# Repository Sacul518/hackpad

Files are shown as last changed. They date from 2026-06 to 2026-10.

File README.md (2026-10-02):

# Hackpad

A custom 9-key mechanical macropad with a rotary encoder and OLED display, built around the **Seeed XIAO RP2040**. Designed from scratch in KiCad as part of [Hack Club's Hackpad YSWS](https://hackpad.hackclub.com/).

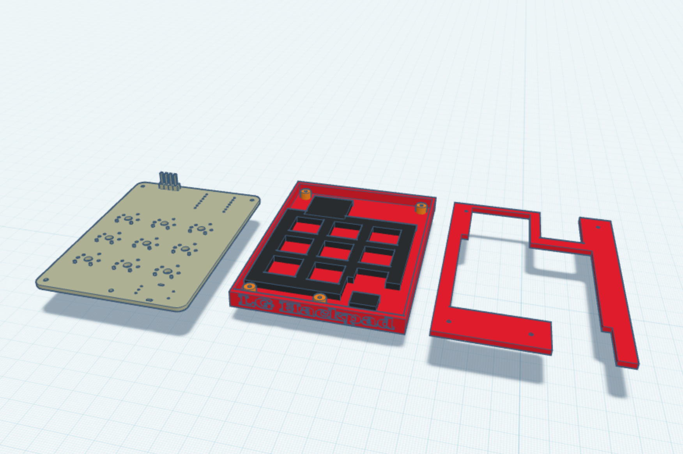
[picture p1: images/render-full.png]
Full render — PCB, case tray and top frame


## Inspiration & challenges

I wanted a macropad that isn't just static keys but actually adapts to what I'm
doing — so the **rotary encoder browses through profiles** (turn to preview on
the OLED, click to confirm) and **every one of the 9 keys is freely
configurable** through a desktop app, either as a key combo or a custom script.

Biggest challenges as a first-timer:
- **Routing a 2-layer board by hand** around the matrix diodes and the encoder
  without crossing nets, while keeping a clean GND pour.
- **Fitting everything under 100 × 100 mm** — I had to shrink the outline and
  move the bottom edge and mounting holes without breaking the carefully placed
  switch matrix (final size: **68 × 99.68 mm**).
- **An open case without print supports** — exposed XIAO RP2040 because it looks
  cool, plus an anti-flex support grid under the PCB so the board doesn't bend
  when pressing keys.

## Features

- **3×3 mechanical switch matrix** (9× Cherry MX–compatible keys) with per-key 1N4148 diodes for full n-key rollover
- **Rotary encoder** (EC11) with push button — for volume, scrolling, etc.
- **0.96" OLED display** (SSD1306, I²C) for layer/status info
- **Seeed XIAO RP2040** microcontroller (through-hole)
- Custom PCB + 3D-printed case

## Bill of materials (BOM)

| # | Qty | Part | Notes |
|---|-----|---|---|
| 1 | 1 | Seeed XIAO RP2040 | main MCU (through-hole) |
| 2 | 9 | Cherry MX–compatible switch | PCB-mount, 3×3 matrix |
| 3 | 9 | 1N4148 diode | THT, per-key (COL→ROW), n-key rollover |
| 4 | 1 | EC11 rotary encoder w/ push switch | profile browser |
| 5 | 1 | SSD1306 0.96" OLED (I²C, 4-pin) | status / profile preview |
| 6 | 1 | Custom PCB (2-layer) | 68 × 99.68 mm |
| 7 | 1 | 3D-printed case (tray + open top frame) | PLA, no supports |
| 8 | 4 | M2 screw | case mounting |
| 9 | 9 | Keycap (DSA) + 1 encoder knob | from the kit |

A machine-readable version is also provided as [`bom.csv`](bom.csv).

### Pin mapping (XIAO RP2040)

| Function | Pin | | Function | Pin |
|---|-----|---|---|-----|
| COL0 | D0 | | ROW0 | D3 |
| COL1 | D1 | | ROW1 | D6 |
| COL2 | D2 | | ROW2 | D7 |
| Encoder A | D8 | | OLED SDA | D4 |
| Encoder B | D9 | | OLED SCL | D5 |
| Encoder SW | D10 | | | |

Matrix is wired **COL2ROW**: column → switch → diode anode, diode cathode → row.

## Gallery

| Schematic | PCB | Case |
|---|-----|---|
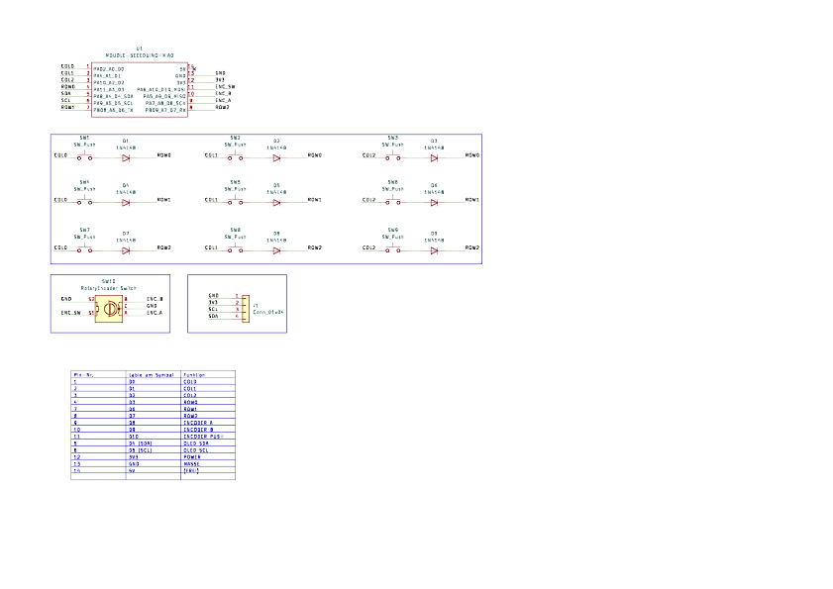
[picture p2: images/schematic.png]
Schematic
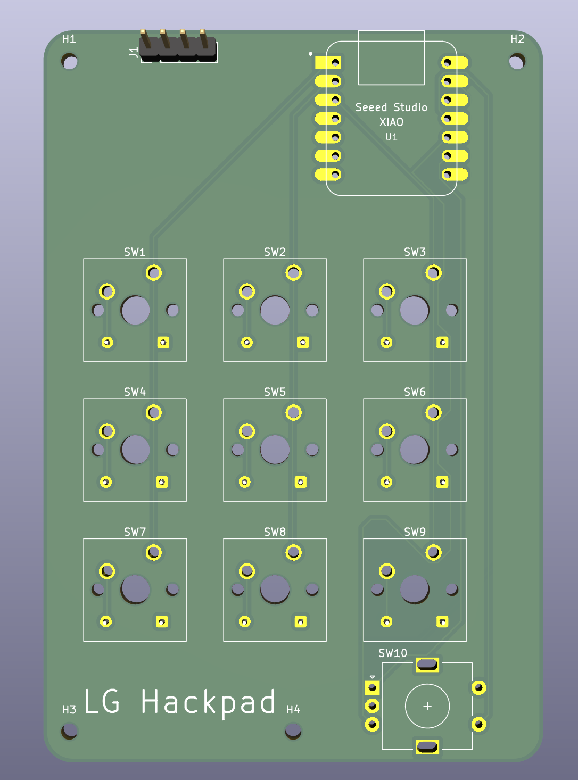
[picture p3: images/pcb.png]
PCB
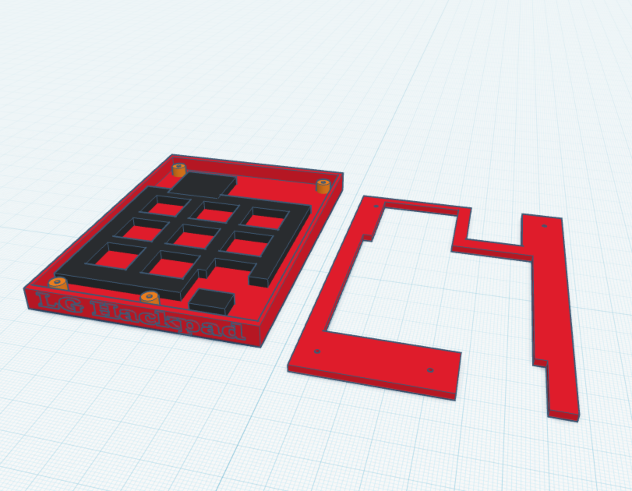
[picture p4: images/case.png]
Case
|  |  |  |

## Project status

- [x] Schematic (ERC clean)
- [x] PCB layout — components placed, all nets routed
- [x] Rounded board outline (68 × 99.68 mm — under the 100 × 100 mm limit)
- [x] Mounting holes (4× M2)
- [x] GND copper pour (both layers)
- [x] DRC clean (apart from intentional diode-under-switch placement)
- [x] STEP 3D model exported (for case design)
- [x] Case — bottom tray (Tinkercad: walls, USB cutout, 4× M2 standoffs, PCB anti-flex support grid)
- [x] Case — top frame (open design, XIAO RP2040 exposed, 9× switch openings, encoder cutout, name/branding)
- [x] Case fitted to resized PCB & exported as STL (no-supports, printer-friendly orientation)
- [x] Firmware — CircuitPython base (matrix, encoder profile-browser, OLED, JSON-config macro engine)
- [ ] Firmware — hardware bring-up & test (pending physical board)
- [x] Configurator app — base GUI (Python + CustomTkinter: device detect, profiles, key editor, save to device)
- [x] Configurator app — full 100% virtual keyboard (QWERTZ, per-OS Win/Mac layout), scrollable profiles, double-click build (PyInstaller)
- [ ] Configurator app — cross-OS packaging (Windows .exe / Linux build)

## Repository layout

```
production/                ► everything needed to build one: case/gerbers.zip,
                             both case STLs, final firmware, BOM
hackpad.kicad_pro          KiCad project
hackpad.kicad_sch          Schematic
hackpad.kicad_pcb          PCB layout
KiCAD-lib/                 Project-specific footprints
export/hackpad.step        3D model of the PCB (CAD reference for the case)
export/hackpad-gerbers.zip Fabrication gerbers + drill (production, ready for JLCPCB)
Case/Hackpad-case.stl      Case source model (both parts in one Tinkercad export)
Case/Hackpad-case.step     Same case as STEP (for CAD inspection)
firmware/                  CircuitPython firmware (config-driven macro engine)
app/                       Configurator GUI (Python + CustomTkinter)
docs/                      config.json schema & script-syntax contract
images/                    Renders & photos (used in this README)
```

## Building

Everything you need to build one is in **[`production/`](production/)**:

- `production/case/gerbers.zip` — send as-is to JLCPCB (2-layer, 68 × 99.68 mm)
- `production/case/` — the **2 parts to 3D print**, as separate STLs
  (bottom tray + top plate), no supports needed
- `production/firmware/` — the final CircuitPython firmware, ready to copy onto
  the `CIRCUITPY` drive (Adafruit libraries included)
- `production/bom.csv` — parts list

Step-by-step instructions: [`production/README.md`](production/README.md).

## Use of AI in this project

I want to be transparent about how AI (Claude) was used here:

- **PCB design** — done entirely by me, by hand, in KiCad. The AI did **not**
  create the schematic or the board layout. It only made suggestions and
  answered questions when I got stuck (e.g. how to shrink the outline under
  100 mm without moving my mounting holes). Every footprint placement, trace
  and the final layout decisions are mine.
- **3D case** — designed entirely by me in Tinkercad. The AI did **not** model
  the case. It only answered questions about the program's rules (size limits,
  the no-supports requirement, tolerances) and reviewed my exported STL against
  those rules. The geometry, the open design and the support structure are mine.
- **Firmware** — here the AI did the heavy lifting: I set the direction and the
  vision (encoder browses profiles, OLED status screen, each of the 9 keys
  freely assignable, JSON-config-driven macro engine), and the AI implemented
  the CircuitPython code to match that.
- **Configurator app** — built collaboratively from my concept (the layout and
  feature set come from my sketch/PDF), with the AI writing much of the
  CustomTkinter code.

In short: **hardware (PCB + case) is my own work**; the AI assisted mainly on
the software side and as a sounding board for questions.

## Acknowledgements

Built as part of the **Hack Club Hackpad** program. Hardware design and layout
done by hand in KiCad — this was my first PCB. 🎉

## License

[MIT](LICENSE) — for both the software (firmware + app) and the hardware
(PCB + case). You're free to use, modify and share it; just keep the credit.

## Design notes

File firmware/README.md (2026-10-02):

# Hackpad Firmware (CircuitPython)

Firmware für den Hackpad-Macropad (Seeed XIAO RP2040). Liest eine `config.json`,
scannt die 3×3-Matrix, blättert per Encoder durch Profile (OLED-Feedback) und
führt pro Taste konfigurierbare Aktionen aus (Tastenkombis, getippte Strings,
Media-Tasten, Custom-Sequenzen).

## Aufbau

```
boot.py            Aktiviert HID (Tastatur + Media), Laufwerk bleibt host-beschreibbar
code.py            Hauptprogramm: Setup + Hauptschleife
config.json        Beispiel-Konfiguration (wird später von der App überschrieben)
hackpad/
  keymap.py        Tastennamen -> HID-Codes (gemeinsamer Wortschatz mit der App)
  config.py        config.json laden/validieren (mit Fallback)
  macros.py        Macro-Engine: führt eine Aktion aus
  profiles.py      Profil-Browser + NVM-Persistenz
  display.py       OLED-Statusanzeige (läuft auch ohne OLED)
  encoder.py       Drehknopf-Auswertung für D8/D9 (GPIO2/GPIO4)
lib/               Adafruit-Bibliotheken (siehe unten — NICHT im Repo)
```

Schema der `config.json`: siehe [`../docs/config-schema.md`](../docs/config-schema.md).

## Installation (wenn die Hardware da ist)

1. **CircuitPython flashen**
   - XIAO RP2040 per USB-C anstecken.
   - Den **BOOT**-Knopf gedrückt halten, kurz **RESET** tippen, BOOT loslassen
     (oder bei nur einem Knopf: BOOT halten beim Einstecken). Es erscheint ein
     Laufwerk `RPI-RP2`.
   - Die passende **`.uf2`** von circuitpython.org (Board: *Seeed XIAO RP2040*)
     auf `RPI-RP2` ziehen. Das Board startet neu → Laufwerk `CIRCUITPY`.

2. **Bibliotheken kopieren** (CircuitPython Library Bundle von
   circuitpython.org/libraries, passend zur CP-Version). Nach `CIRCUITPY/lib/`:
   - `adafruit_hid/`
   - `adafruit_displayio_ssd1306.mpy`
   - `adafruit_display_text/`
   - `adafruit_ticks.mpy`
   - (`i2cdisplaybus`/`displayio` sind in CircuitPython 9+ eingebaut)

3. **Firmware kopieren**: `boot.py`, `code.py`, `config.json` und den Ordner
   `hackpad/` nach `CIRCUITPY/`.

4. **Fertig** — das Board startet die Firmware automatisch. Änderungen an
   Dateien (auch an `config.json`) lösen einen Auto-Reload aus.

## Bring-up-Checkliste (erster Hardware-Test)

- [ ] Serielle Konsole öffnen (Mu-Editor, oder `tio`/`screen` auf das
      USB-Modem-Device) → Boot-Meldungen sichtbar?
- [ ] Jede der 9 Tasten in einem Texteditor drücken → kommt die erwartete
      Aktion? Falls falsche Taste reagiert: `KEY_MAP` in `code.py` anpassen.
- [ ] Falls **gar keine** Taste reagiert: `columns_to_anodes` in `code.py`
      umdrehen (Diodenrichtung).
- [ ] Encoder drehen → OLED zeigt Profil-Vorschau; Klick → Profil wird aktiv.
- [ ] OLED zeigt das aktive Profil. Falls dunkel: I2C-Adresse (0x3C/0x3D) in
      `hackpad/display.py` prüfen.

## Debuggen ohne Hardware

Die Python-Syntax lässt sich lokal prüfen:
```
python3 -m py_compile boot.py code.py hackpad/*.py
```
Echte Funktion (HID, Matrix, OLED) braucht das CircuitPython-Board.

Encoder-Signalfolgen (beide Richtungen, Prellen, Startzustände, Pufferüberlauf):
```
python3 -m unittest discover -s tests -p 'test_encoder.py' -v
```
Den Befehl im Projektordner `hackpad/` ausführen. Der Drehknopf wird über
`keypad.Keys` alle 1 ms im Hintergrund gescannt. `rotaryio` lässt sich auf
dieser Platine nicht verwenden: D8 und D9 entsprechen GPIO2 und GPIO4,
auf dem RP2040 verlangt `rotaryio` jedoch direkt benachbarte GPIOs.
Sehr schnelle Drehungen können mit dem 1-ms-Scan verloren gehen; die echte
Bedienung muss deshalb zusätzlich am aufgebauten Hackpad geprüft werden.

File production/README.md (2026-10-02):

# Production files

Everything needed to actually build this Hackpad — PCB fabrication, 3D printing
and flashing — in one folder.

```
case/gerbers.zip                        PCB fabrication files (JLCPCB-ready)
case/Hackpad-Case-1-Bottom-Tray.stl     3D print part 1 of 2
case/Hackpad-Case-2-Top-Plate.stl       3D print part 2 of 2
firmware/                               Final firmware, ready to drag onto CIRCUITPY
bom.csv                                 Bill of materials
```

## 1. PCB — `case/gerbers.zip`

2-layer board, **68 × 99.68 mm**, 1.6 mm FR4, HASL. Upload the zip as-is to
JLCPCB (or any fab) — no changes needed. Contents:

| File | Layer |
|---|---|
| `hackpad-F_Cu.gbr` / `hackpad-B_Cu.gbr` | copper top / bottom |
| `hackpad-F_Mask.gbr` / `hackpad-B_Mask.gbr` | solder mask top / bottom |
| `hackpad-F_Silkscreen.gbr` / `hackpad-B_Silkscreen.gbr` | silkscreen top / bottom |
| `hackpad-Edge_Cuts.gbr` | board outline |
| `hackpad.drl` | drill file |
| `hackpad-job.gbrjob` | Gerber job file |

No paste layer — the board is 100 % through-hole and hand-soldered.

## 2. Case — 2 printed parts

Both parts are separate, watertight STLs, already oriented flat on the build
plate. **No supports needed.**

| Part | File | Size (X × Y × Z) |
|---|---|---|
| Bottom tray | `case/Hackpad-Case-1-Bottom-Tray.stl` | 73.0 × 106.5 × 7.0 mm |
| Top plate | `case/Hackpad-Case-2-Top-Plate.stl` | 73.0 × 106.0 × 2.0 mm |

Print settings I used: PLA, 0.2 mm layer height, 3 walls, 20 % infill, no
supports, no brim. The tray contains the 4× M2 standoffs (self-tapping Ø1.7 mm
holes), the encoder support boss and the anti-flex support grid under the PCB —
all printed in one piece with the tray.

Assembly: PCB drops into the tray onto the standoffs, top plate goes on top,
4× M2 screws from the top hold the stack together.

## 3. Firmware — `firmware/`

The Hackpad runs **CircuitPython**, so there is no compiled binary — the `.py`
files *are* the final firmware. This folder is the complete, ready-to-use
`CIRCUITPY` drive content, including the Adafruit libraries.

```
boot.py            enables HID (keyboard + consumer control)
code.py            main program: matrix scan, encoder, OLED, main loop
config.json        default configuration (Media + Coding profile)
hackpad/           macro engine, keymap, config loader, profiles, OLED display
lib/               Adafruit libraries (CircuitPython 10.x, .mpy)
```

### Flashing

1. Plug in the XIAO RP2040, hold **BOOT**, tap **RESET**, release BOOT — the
   drive `RPI-RP2` appears.
2. Drag the **CircuitPython 10.x `.uf2`** for *Seeed XIAO RP2040*
   (from [circuitpython.org](https://circuitpython.org/board/seeeduino_xiao_rp2040/))
   onto `RPI-RP2`. The board reboots as `CIRCUITPY`.
3. Copy **everything inside this `firmware/` folder** (`boot.py`, `code.py`,
   `config.json`, `hackpad/`, `lib/`) onto the `CIRCUITPY` drive.
4. Done — the firmware starts automatically. Editing any file (including
   `config.json`) triggers an auto-reload.

> The bundled `lib/` is the **10.x** `.mpy` build, so use CircuitPython 10.x.
> With CircuitPython 9.x, replace `lib/` with the matching 9.x bundle.

Keys are reconfigured with the desktop app in [`../app/`](../app/), which writes
a new `config.json` straight to the `CIRCUITPY` drive. The config format is
documented in [`../docs/config-schema.md`](../docs/config-schema.md).

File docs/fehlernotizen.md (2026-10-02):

# Fehler beim ersten Start — 02.10.2026

## Beobachtung und bestätigte Ursache

Das OLED zeigte die CircuitPython-Fehlerkonsole statt der Hackpad-Anzeige.
Ein Neustart über USB reproduzierte auf dem aufgebauten XIAO RP2040:

```text
File "code.py", line 66, in main
RuntimeError: Pins must be sequential GPIO pins
```

Die Firmware verwendete `rotaryio.IncrementalEncoder(board.D8, board.D9)`.
D8/D9 sind auf diesem Board GPIO2/GPIO4. Die RP2040-Implementierung von
`rotaryio` verlangt direkt benachbarte GPIOs. Die Platinenanschlüsse bleiben
unverändert; die Auswertung muss diese Pinbelegung unterstützen.

Quellen: [Seeed: Pinbelegung des XIAO RP2040](https://wiki.seeedstudio.com/XIAO-RP2040/),
[CircuitPython: Erklärung der GPIO-Einschränkung](https://github.com/adafruit/circuitpython/issues/5334)
und [keypad-API für CircuitPython 10.3.1](https://docs.circuitpython.org/en/10.3.1/shared-bindings/keypad/index.html).

## Korrektur

`firmware/hackpad/encoder.py` scannt beide Kontakte über `keypad.Keys` mit
internen Pull-ups alle 1 ms im Hintergrund. Vier gültige Übergänge ergeben
einen Positionsschritt. Rückwärtsbewegungen und Kontaktprellen werden
verrechnet. Gleichzeitige Änderungen beider Kontakte sowie ein voller
Ereignispuffer führen zur Synchronisierung statt zu erfundenen Drehschritten.
Bei sehr schnellem Drehen können Übergänge zwischen zwei Scans verloren gehen.

`code.py` verwendet diese Auswertung. Quellfirmware und Produktionskopie
wurden aktualisiert; `code.py` und `hackpad/encoder.py` wurden auf das
angeschlossene `CIRCUITPY`-Laufwerk kopiert und bytegenau verglichen.
Die bisherige `code.py` ist unter
`/private/tmp/hackpad-before-encoder-fix-20261002/code.py` gesichert.

## Verifikation

- Zwölf lokale Signaltests bestanden: Stillstand, beide Richtungen,
  Teilschritte, Prellen, Richtungswechsel, gleichzeitige Änderungen,
  fehlende Übergänge, alle vier Startzustände, Pufferüberlauf, mehrere
  gepufferte Umdrehungen, Pinfreigabe und identische Produktionskopie.
- Syntax aller neun Python-Dateien je Firmware-Ordner geprüft.
- Echter Start mit CircuitPython 10.3.1 auf dem XIAO RP2040:
  `Hackpad bereit. Profile: 2`; anschließend zwölf Sekunden ohne Traceback
  oder OLED-Initialisierungswarnung.
- Nach dem Aufspielen sendete Lucas `Hallo vom Hackpad!`, genau den für die
  Texttaste konfigurierten Text. Damit ist die Textausgabe am Mac auch im
  Bedienungstest bestätigt.
- Drehknopf, Klick und die übrigen acht Tasten sind noch nicht bestätigt;
  die lokalen Signaltests ersetzen diese physischen Bedienungstests nicht.

## Regel für weitere Änderungen

Bei RP2040-Pinbelegungen die tatsächlichen GPIO-Nummern prüfen, nicht nur
die D-Nummern. Nach jeder Firmware-Änderung den echten Start über USB prüfen;
ein erfolgreicher Dateitransfer oder Syntaxcheck reicht nicht aus.

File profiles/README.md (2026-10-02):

# Profile für Lucas' Mac

`mac-qwertz.json` enthält Media, Code, Alltag, Browser und das bisherige
Profil `test`. Die Konfiguration vor der Erweiterung liegt unter
`backups/2026-10-02-before-mac-profiles.json`.

Die Tasten werden von oben links nach unten rechts nummeriert:

```text
1  2  3
4  5  6
7  8  9
```

| Taste | Media | Code (VS Code) | Alltag | Browser |
|---|---|---|---|---|
| 1 | Vorheriger Titel | Kopieren | Kopieren | Neuer Tab |
| 2 | Play / Pause | Einfügen | Einfügen | Geschlossenen Tab wiederherstellen |
| 3 | Nächster Titel | Ausschneiden | Ausschneiden | Tab schließen |
| 4 | Leiser | Rückgängig | Rückgängig | Vorheriger Tab |
| 5 | Stumm | Wiederholen | Wiederholen | Neu laden |
| 6 | Lauter | Speichern | Alles markieren | Nächster Tab |
| 7 | Pfeil links | Befehlspalette | Spotlight | Adresszeile |
| 8 | Stop | Datei schnell öffnen | Screenshot eines Bereichs | Seite durchsuchen |
| 9 | Pfeil rechts | Dokument formatieren | Emoji-Auswahl | Escape |

Drehknopf drehen → Profil vorschauen. Drücken → Profil bestätigen.
Die Auswahl bleibt nach dem Neustart erhalten. Das Pack startet bei der
Installation mit Media; die Firmware speichert die Auswahl zusätzlich im NVM.

Die Belegungen sind für **macOS mit deutscher QWERTZ-Eingabequelle** ausgelegt.
Rückgängig ist ⌘Z, Wiederholen ⇧⌘Z. Dafür steht in der JSON der rohe HID-Code
`Y`: Diese physische Taste trägt auf dem deutschen Layout ein Z, wie bereits
im Tastaturlayout der Konfigurator-App hinterlegt.

Code benutzt die Standardbelegung von VS Code. Eigene Tastenkürzel können
abweichen. Formatieren braucht einen passenden Formatter für die Datei.
Browser nutzt übliche macOS-Browserkürzel, anhand von Safari geprüft.
Medientasten brauchen einen Player, der die jeweiligen Befehle unterstützt;
die Pfeiltasten bleiben normale Pfeiltasten und ihre Wirkung hängt vom Player ab.

Quellen: [VS Code: Standardkürzel](https://code.visualstudio.com/shortcuts/keyboard-shortcuts-macos.pdf),
[macOS: Tastenkürzel](https://support.apple.com/en-us/102650),
[Safari: Tastenkürzel](https://support.apple.com/en-gb/guide/safari/cpsh003/mac).

## Installationsstand am 02.10.2026

Die JSON, 9 Tasten je Profil und alle verwendeten Tastennamen wurden lokal
geprüft. Die alte Konfiguration ist gesichert. Die Datei wurde auf das
Hackpad kopiert und bytegenau verifiziert. Beide App-Arbeitskopien wurden
aktualisiert; nach dem Neustart zeigt die App die vier neuen Profile und
`Media (1/5)` an.

Der erste serielle Test erreichte vor dem Schreiben noch keinen REPL-Prompt;
die Dateiänderung löste einen automatischen Neustart aus. Anschließend
reagierte die Konsole auch nach explizitem Setzen von DTR/RTS nicht auf die
REPL-Anforderung. Nach einem physischen Reset bestätigte Lucas die Anzeige
`Hackpad / Media`. Der Start und das aktive Media-Profil sind damit auch am
Gerät bestätigt. Die serielle Prüfung der Tastennamen mit den echten
Board-Bibliotheken wurde nicht abgeschlossen. Alle Aktionen in ihren
jeweiligen Mac-Programmen müssen noch mit den physischen Tasten getestet werden.

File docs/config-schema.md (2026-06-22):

# Hackpad config.json — Schema & Script-Syntax

Dies ist der **Vertrag zwischen der Konfigurator-App und der Firmware**. Die App
schreibt die `config.json` auf das CIRCUITPY-Laufwerk; die Firmware liest sie nur
und führt rohe HID-Codes aus. **Die ganze OS-Logik liegt in der App** — die
Firmware ist OS-neutral.

## Struktur

```jsonc
{
  "version": 1,
  "active_profile": 0,          // Start-Profil-Index (Firmware nutzt NVM als Override)
  "profiles": [
    {
      "name": "Coding",          // wird auf dem OLED angezeigt
      "target_os": "mac",        // "mac" | "windows" | "linux" — nur Info; Codes sind schon aufgelöst
      "keys": [                  // genau 9 Einträge, Index 0..8 = physische Tasten 1..9
        { "label": "Copy", "action": { ... } }
      ]
    }
  ]
}
```

## Action-Typen

| type | Felder | Wirkung |
|---|---|---|
| `combo` | `keys: [name, ...]` | Alle Tasten gleichzeitig drücken + loslassen (z. B. `["GUI","C"]` = Cmd+C) |
| `key` | `key: name` | Eine einzelne Taste |
| `string` | `text: "..."` | Text Zeichen für Zeichen tippen (super schnell) |
| `media` | `code: name` | Eine Media-/Consumer-Taste (z. B. `PLAY_PAUSE`) |
| `sequence` | `steps: [action, ...]`| Schritte nacheinander; jeder Schritt ist `key`/`combo`/`string`/`media` |
| `null` | — | Taste tut nichts |

## Tastennamen

Entsprechen den `adafruit_hid.Keycode`-Attributen: `A`–`Z`, `ZERO`–`NINE`,
`F1`–`F12`, `ENTER`, `ESCAPE`, `TAB`, `SPACEBAR`, `BACKSPACE`, `DELETE`,
`LEFT_ARROW`/`RIGHT_ARROW`/`UP_ARROW`/`DOWN_ARROW`, `HOME`/`END`/`PAGE_UP`/`PAGE_DOWN`.

Modifier: `GUI` (= Cmd/Win/Super), `CONTROL`, `SHIFT`, `ALT`.

Freundliche Aliase (von der Firmware akzeptiert): `Return`→`ENTER`, `Cmd`/`Win`→`GUI`,
`Ctrl`→`CONTROL`, `Opt`/`Option`→`ALT`, `Esc`, `Left`/`Right`/`Up`/`Down`, `Space`.

Media-Namen: `PLAY_PAUSE`, `MUTE`, `VOLUME_UP`, `VOLUME_DOWN`, `NEXT_TRACK`,
`PREV_TRACK`, `STOP`.

## Script-Syntax (nur in der App)

Im Custom-Script-Editor tippt man Aktionen kompakt; **die App parst das** und
schreibt daraus die strukturierte JSON oben. Die Firmware sieht nie diesen Text.

| Eingabe | wird zu |
|---|---|
| `(Return)` `(Left arrow)` | `key`-Schritte (Tastendrücke nacheinander) |
| `"text"` (doppelte Quotes) | `string` — Zeichen für Zeichen super schnell getippt |
| `'text'` (einfache Quotes) | `string` — "auf einmal einfügen" (v1: ebenfalls schnell getippt) |

Beispiel: `(Return) "fertig" (Return)` →
```json
{ "type": "sequence", "steps": [
  { "type": "key", "key": "ENTER" },
  { "type": "string", "text": "fertig" },
  { "type": "key", "key": "ENTER" }
]}
```

## OS-Übersetzung (App-Aufgabe)

Die App übersetzt hohe Aktionen je nach `target_os` in rohe Codes, z. B.
„Kopieren": `GUI+C` (mac) bzw. `CONTROL+C` (windows/linux). So kann man von
jedem Rechner aus Profile für jedes OS bauen.

## Persistenz des aktiven Profils

Die Firmware speichert das zuletzt **bestätigte** Profil in
`microcontroller.nvm` (1 Byte). Das überlebt Neustart/Reload, ohne das
USB-Laufwerk für den Host schreibzuschützen.

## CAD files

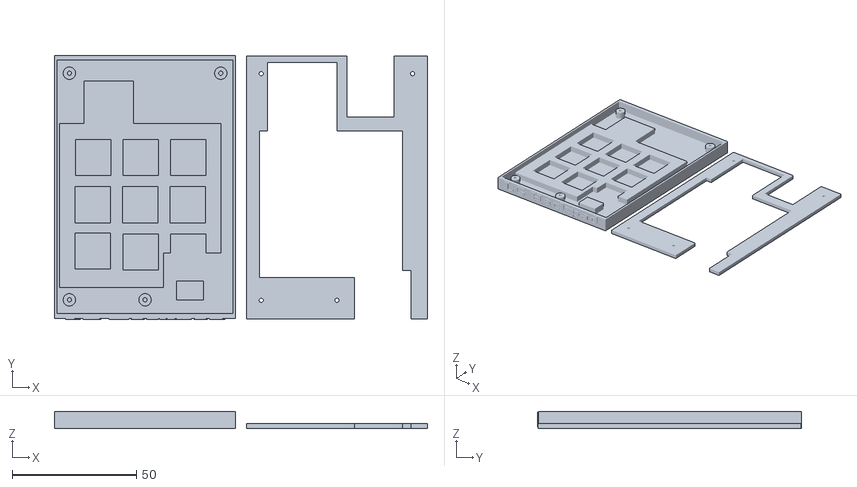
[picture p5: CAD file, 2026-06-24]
Case/Hackpad-case.stl
150.3 x 106.5 x 7.00

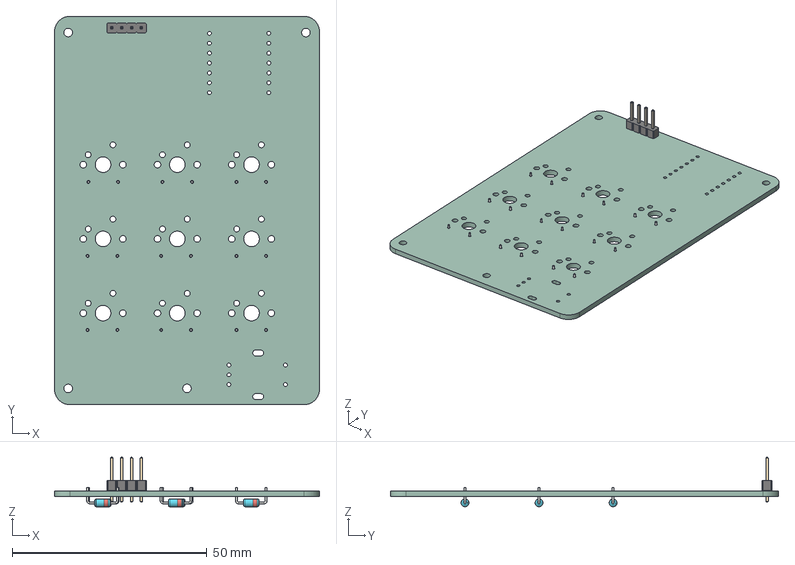
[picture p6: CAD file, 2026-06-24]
export/hackpad.step
68.0 x 99.7 x 12.7 mm
PinHeader_1x04_P254mm_Vertical
D_DO-35_SOD27_P7.62mm_Horizontal x 9
hackpad_PCB

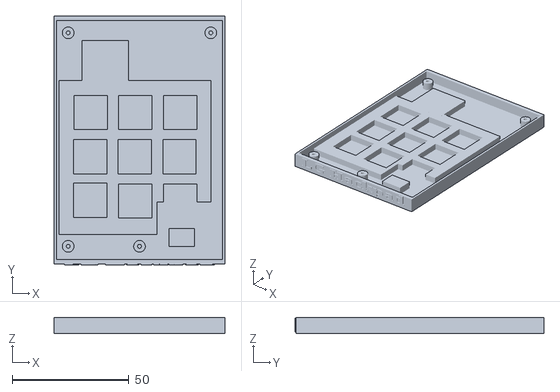
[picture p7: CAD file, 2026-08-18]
production/case/Hackpad-Case-1-Bottom-Tray.stl
73.0 x 106.5 x 7.00

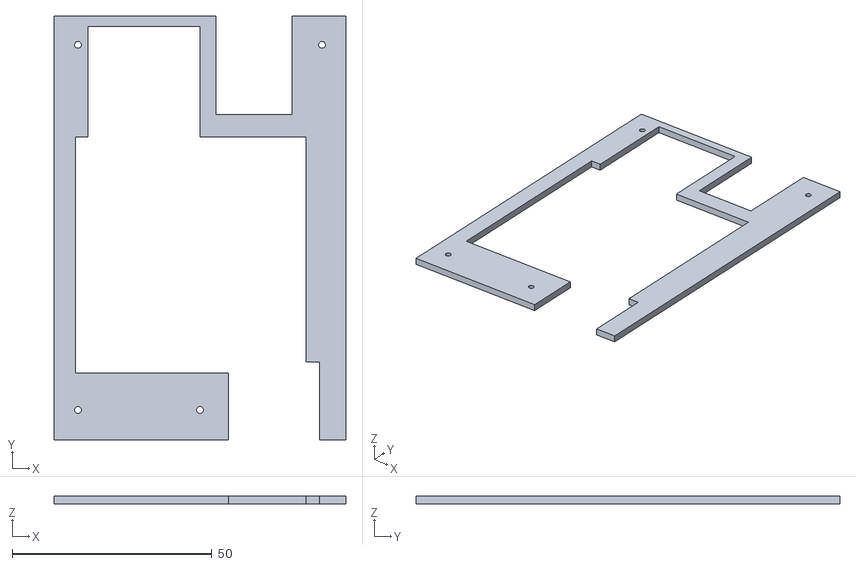
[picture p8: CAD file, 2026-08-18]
production/case/Hackpad-Case-2-Top-Plate.stl
73.0 x 106.0 x 2.00

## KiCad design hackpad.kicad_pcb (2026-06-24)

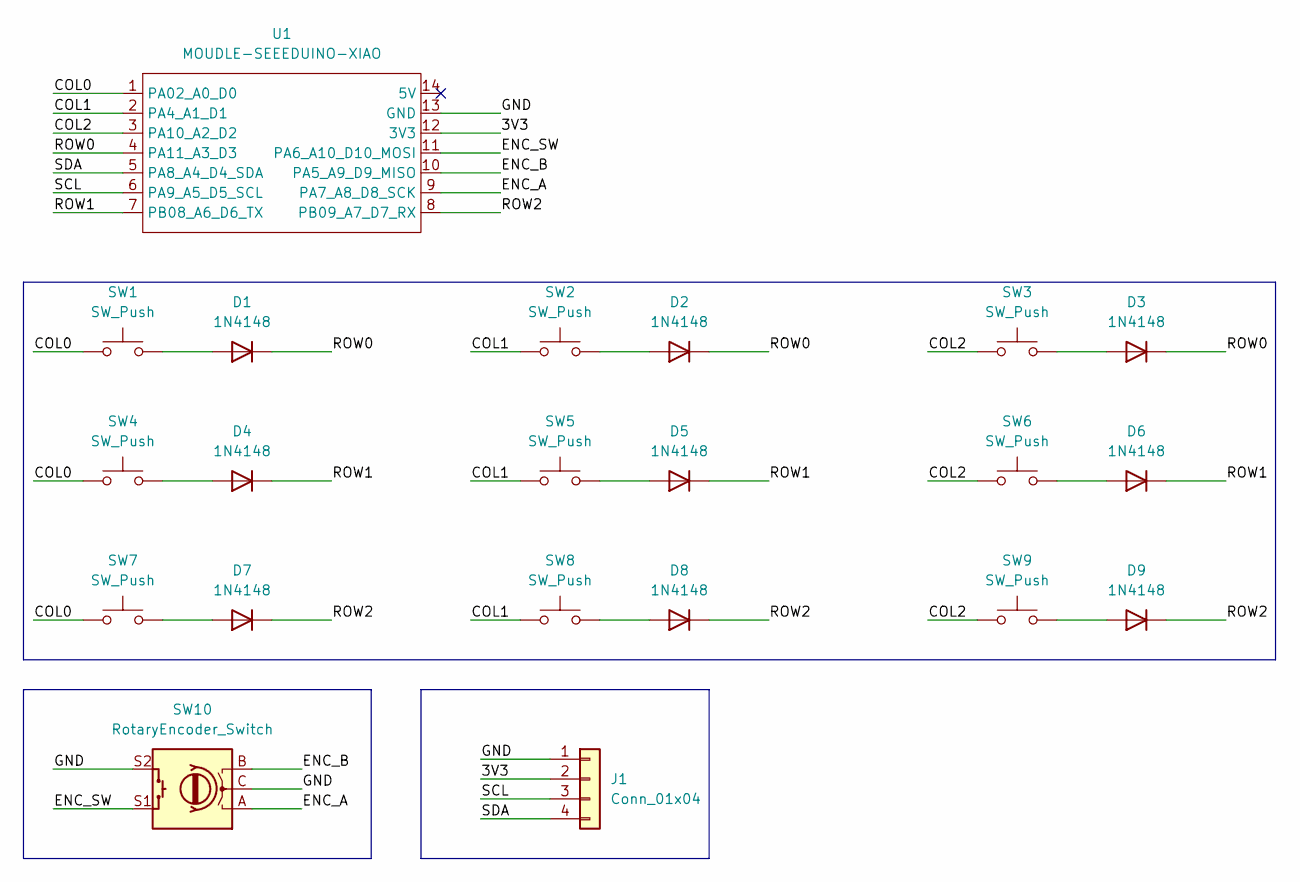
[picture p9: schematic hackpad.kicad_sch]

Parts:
D1, D2, D3, D4, D5, D6, D7, D8, D9: 1N4148; D_DO-35_SOD27_P7.62mm_Horizontal
J1: Conn_01x04; PinHeader_1x04_P2.54mm_Vertical
SW1, SW2, SW3, SW4, SW5, SW6, SW7, SW8, SW9: SW_Push; SW_Cherry_MX_1.00u_PCB
SW10: RotaryEncoder_Switch; RotaryEncoder_Alps_EC11E-Switch_Vertical_H20mm
U1: MOUDLE-SEEEDUINO-XIAO; XIAO-Generic-Hybrid-14P-2.54-21X17.8MM

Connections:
/3V3: J1.2, U1.12 (3V3)
/COL0: SW1.1, SW4.1, SW7.1, U1.1 (PA02_A0_D0)
/COL1: SW2.1, SW5.1, SW8.1, U1.2 (PA4_A1_D1)
/COL2: SW3.1, SW6.1, SW9.1, U1.3 (PA10_A2_D2)
/ENC_A: SW10.A, U1.9 (PA7_A8_D8_SCK)
/ENC_B: SW10.B, U1.10 (PA5_A9_D9_MISO)
/ENC_SW: SW10.S1, U1.11 (PA6_A10_D10_MOSI)
/GND: J1.1, SW10.C, SW10.S2, U1.13 (GND)
/ROW0: D1.1 (K), D2.1 (K), D3.1 (K), U1.4 (PA11_A3_D3)
/ROW1: D4.1 (K), D5.1 (K), D6.1 (K), U1.7 (PB08_A6_D6_TX)
/ROW2: D7.1 (K), D8.1 (K), D9.1 (K), U1.8 (PB09_A7_D7_RX)
/SCL: J1.3, U1.6 (PA9_A5_D5_SCL)
/SDA: J1.4, U1.5 (PA8_A4_D4_SDA)
unnamed: D1.2 (A), SW1.2
unnamed: D2.2 (A), SW2.2
unnamed: D3.2 (A), SW3.2
unnamed: D4.2 (A), SW4.2
unnamed: D5.2 (A), SW5.2
unnamed: D6.2 (A), SW6.2
unnamed: D7.2 (A), SW7.2
unnamed: D8.2 (A), SW8.2
unnamed: D9.2 (A), SW9.2

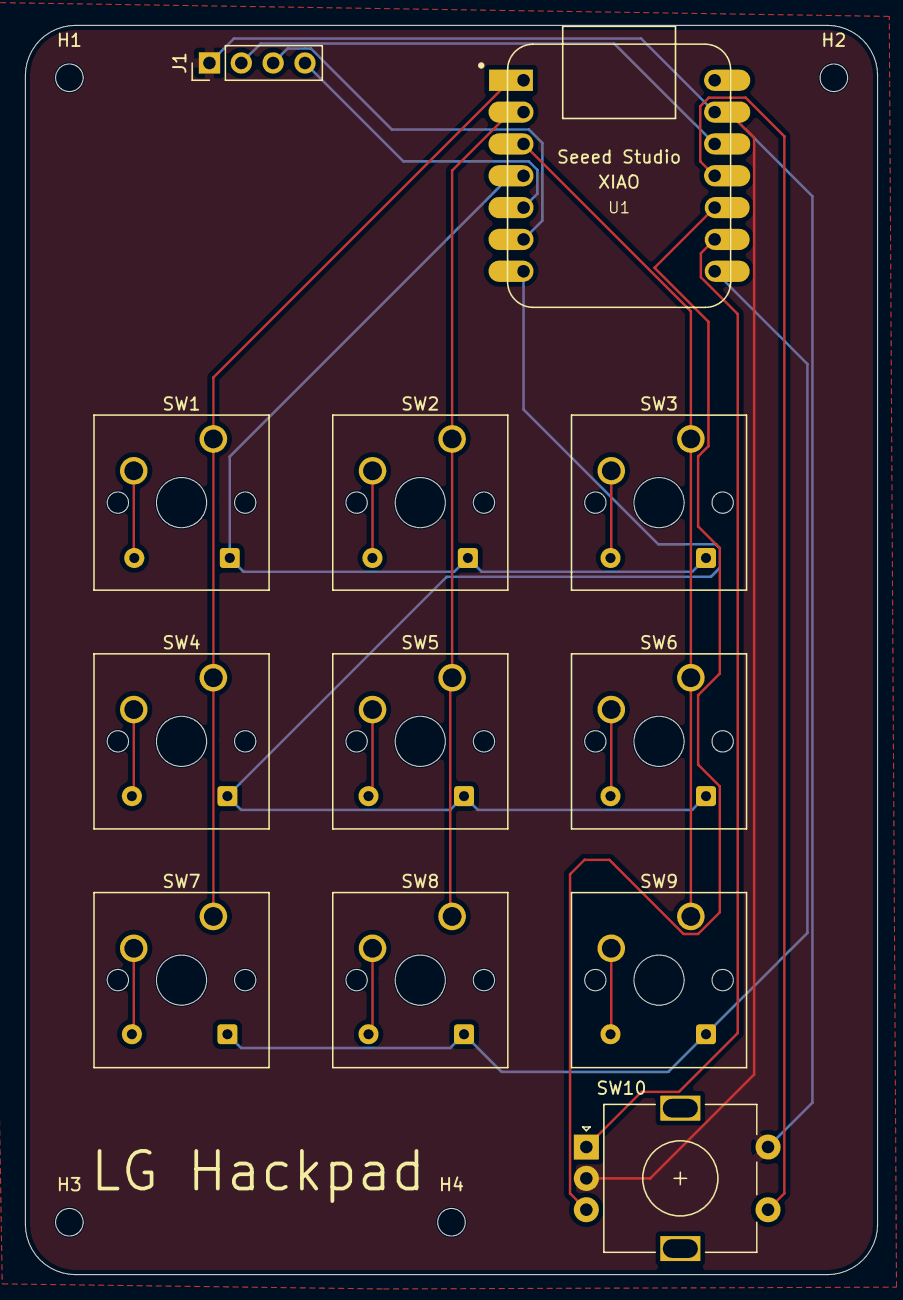
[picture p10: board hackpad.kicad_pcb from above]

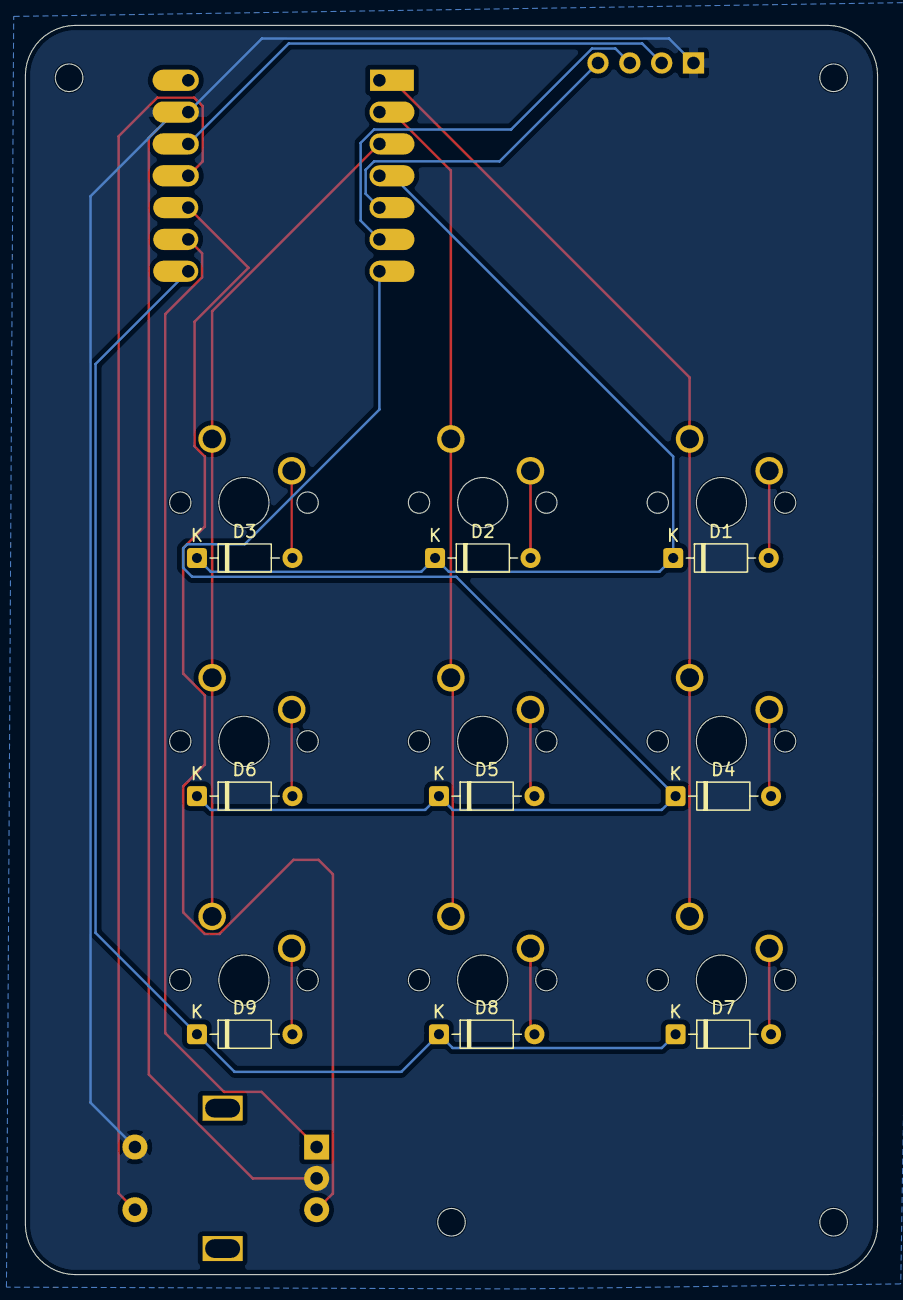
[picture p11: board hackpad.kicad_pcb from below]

Board: 2 copper layers, 68.0 x 99.7 mm, 25 parts (9 on the bottom side), 22 nets.

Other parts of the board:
H1, H2, H3, H4: MountingHole_2.2mm_M2

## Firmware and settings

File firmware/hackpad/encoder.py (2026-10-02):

"""Quadratur-Encoder fuer die nicht benachbarten GPIOs des XIAO RP2040."""

import time

import keypad


class IncrementalEncoder:
    # D8=GPIO2 und D9=GPIO4: rotaryio verlangt auf dem RP2040 Nachbar-GPIOs.
    # keypad scannt im Hintergrund, auch waehrend ein Makro ausgefuehrt wird.
    _TRANSITIONS = (0, -1, 1, 0, 1, 0, 0, -1, -1, 0, 0, 1, 0, 1, -1, 0)

    def __init__(self, pin_a, pin_b):
        self._keys = keypad.Keys(
            (pin_a, pin_b), value_when_pressed=False, pull=True,
            interval=0.001, max_events=256, debounce_threshold=1,
        )
        self._position = 0
        self._resync()

    def _resync(self):
        self._keys.reset()
        time.sleep(0.003)
        self._state = 3
        self._steps = 0
        event = self._keys.events.get()
        while event is not None:
            self._state = self._event_state(self._state, event)
            event = self._keys.events.get()

    @staticmethod
    def _event_state(state, event):
        mask = 1 << event.key_number
        if event.pressed:
            return state & ~mask
        return state | mask

    def _update(self, state):
        if state == self._state:
            return
        delta = self._TRANSITIONS[(self._state << 2) | state]
        self._state = state
        if delta == 0:
            self._steps = 0
            return
        self._steps += delta
        if self._steps >= 4:
            self._position += 1
            self._steps -= 4
        elif self._steps <= -4:
            self._position -= 1
            self._steps += 4

    @property
    def position(self):
        events = self._keys.events
        if events.overflowed:
            self._resync()
            return self._position
        state = self._state
        timestamp = None
        event = events.get()
        while event is not None:
            # Zwei im selben Scan geaenderte Kontakte haben keine bekannte
            # Reihenfolge; gemeinsam auswerten statt eine Richtung zu erfinden.
            if timestamp is not None and event.timestamp != timestamp:
                self._update(state)
            timestamp = event.timestamp
            state = self._event_state(state, event)
            event = events.get()
        self._update(state)
        return self._position

    def deinit(self):
        self._keys.deinit()

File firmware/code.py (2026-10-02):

"""Hackpad-Firmware (CircuitPython) -- Hauptprogramm.

Liest config.json, scannt die 3x3-Matrix, liest den Encoder und treibt das OLED.
Tastendruck -> fuehrt die konfigurierte Aktion des aktiven Profils aus.
Encoder drehen/klicken -> Profil waehlen.

CircuitPython laedt diese Datei automatisch neu, wenn sich Dateien auf dem
Laufwerk aendern (z.B. wenn die App eine neue config.json schreibt) -> neue
Konfiguration ist sofort aktiv. Das aktive Profil wird im NVM gehalten und
ueberlebt den Reload.

Pin-Mapping (aus dem Schaltplan):
  Spalten COL0/1/2 = D0/D1/D2
  Zeilen  ROW0/1/2 = D3/D6/D7
  Encoder A=D8, B=D9, Klick=D10
  OLED    SDA=D4, SCL=D5  (ueber board.I2C())
"""

import board
import keypad
import usb_hid

from adafruit_hid.keyboard import Keyboard
from adafruit_hid.keyboard_layout_us import KeyboardLayoutUS
from adafruit_hid.consumer_control import ConsumerControl

from hackpad import config as config_mod
from hackpad import display as display_mod
from hackpad.encoder import IncrementalEncoder
from hackpad.macros import MacroEngine
from hackpad.profiles import ProfileManager

# --- Matrix ---------------------------------------------------------------
# COL2ROW: Diodenanode an der Spalte -> columns_to_anodes=True.
# Falls beim Bring-up keine/falsche Tasten kommen: diesen Wert umdrehen.
COLUMN_PINS = (board.D0, board.D1, board.D2)
ROW_PINS = (board.D3, board.D6, board.D7)

# keypad nummeriert: key_number = row * num_columns + column.
# KEY_MAP[key_number] = logische Taste 0..8 (Taste 1..9 in der App).
# Standard = identisch (Zeile oben, links->rechts). Beim Bring-up anpassen,
# falls die physische Anordnung anders ist.
KEY_MAP = (0, 1, 2, 3, 4, 5, 6, 7, 8)


def main():
    # HID-Geraete
    keyboard = Keyboard(usb_hid.devices)
    layout = KeyboardLayoutUS(keyboard)
    consumer = ConsumerControl(usb_hid.devices)
    engine = MacroEngine(keyboard, layout, consumer)

    # Konfiguration + Anzeige + Profile
    cfg, ok = config_mod.load()
    if not ok:
        print("Hinweis: Standard-Konfiguration aktiv (config.json fehlt/ungueltig)")
    oled = display_mod.Display()
    profiles = ProfileManager(cfg, oled)

    # Eingabe-Hardware
    matrix = keypad.KeyMatrix(
        row_pins=ROW_PINS,
        column_pins=COLUMN_PINS,
        columns_to_anodes=True,
    )
    encoder = IncrementalEncoder(board.D8, board.D9)
    enc_button = keypad.Keys((board.D10,), value_when_pressed=False, pull=True)
    last_position = encoder.position

    print("Hackpad bereit. Profile:", profiles.count)

    while True:
        # 1) Tasten der Matrix
        event = matrix.events.get()
        if event and event.pressed:
            key_index = KEY_MAP[event.key_number]
            engine.run(profiles.action_for(key_index))

        # 2) Encoder drehen
        position = encoder.position
        if position != last_position:
            profiles.on_encoder_turn(position - last_position)
            last_position = position

        # 3) Encoder klicken
        benv = enc_button.events.get()
        if benv and benv.pressed:
            profiles.on_encoder_press()


main()

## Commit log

2026-06-21 Initial commit: Hackpad macropad KiCad project
    3x3 switch matrix + EC11 encoder + SSD1306 OLED on a Seeed XIAO RP2040.
    Schematic complete (ERC clean), PCB placed and fully routed, rounded
    63x105mm outline. Includes README and project footprint library.
    [hackpad.kicad_pcb, hackpad.kicad_sch]
2026-06-21 PCB: widen board, round corners, add 4 mounting holes
    Widened the right edge (board now ~68x105mm, symmetric ~6mm margins)
    because the switch grid was only 0.9mm from the original right edge.
    Re-applied 4mm rounded corners. Added 4x M2 mounting holes (H1-H4):
    top-left, top-right, bottom-left and bottom-center. Bottom-right is
    intentionally left open (rotary encoder) — the case will get a support
    boss under the encoder instead.
    [hackpad.kicad_pcb]
2026-06-21 PCB: add GND copper pour on both layers
    Filled F.Cu + B.Cu with a GND zone (thermal reliefs, remove islands).
    Set the encoder common pad (SW10 pad C) to a solid zone connection to
    clear a starved-thermal DRC error. DRC now clean apart from intentional
    diode-under-switch courtyard overlaps and cosmetic silk warnings.
    [hackpad.kicad_pcb]
2026-06-21 README: update progress (mounting holes, GND pour, board size)
2026-06-21 Add STEP 3D model of the PCB for case design
    Exported via kicad-cli. Includes the exact board outline, rounded
    corners and mounting holes as a reference for designing the case.
    [hackpad.step]
2026-06-22 Case: add bottom tray STL (Tinkercad)
    Bottom tray with walls, USB cutout, 4x M2 standoffs and an encoder
    support boss. Update README progress.
    [Hackpad-case-bottom.stl]
2026-06-22 Case: add top plate STL (open/tray-mount style)
    Top plate with a single large switch opening, OLED window and encoder
    cutout; matches the tray footprint (76 x 112.6 mm). Update README.
    [Hackpad-case-top.stl]
2026-06-22 Firmware: CircuitPython base (config-driven macro engine)
    Phase 1 firmware for the XIAO RP2040:
    - code.py: 3x3 matrix scan, encoder profile-browser, OLED, main loop
    - hackpad/: keymap, config loader, macro engine, profile manager, display
    - boot.py: enable Keyboard + Consumer Control HID
    - config.json: sample with Media + Coding profiles
    - docs/config-schema.md: app<->firmware contract (JSON + script syntax)
    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
2026-06-23 App: configurator GUI base (Python + CustomTkinter)
    Phase 3 base: cross-platform CIRCUITPY detection, profile management,
    3x3 key editor with three modes (key-combo / text&script / media),
    OS-aware modifier handling (Cmd vs Ctrl), and save-to-device writing
    config.json. Shares the key-name vocabulary with the firmware.
    Also add digit aliases (1->ONE ...) to firmware keymap.
2026-06-23 App: full 100% virtual keyboard (QWERTZ, per-OS Win/Mac layout)
    Replace the button-list key picker with a real, pixel-positioned 100%
    keyboard: function row on top, number row, QWERTZ main block (ISO),
    nav cluster, numpad, and an OS-specific bottom row. Windows/Linux show
    Ctrl/Win/Alt/AltGr; mac shows control/option/command/fn. Layout rebuilds
    when the profile target OS changes. German key positions map to their
    positional US HID codes (e.g. Z-key -> Keycode.Y).
2026-06-23 App: roomier key spacing + UI polish
    - More breathing room around keys (XUNIT/YUNIT up, KEY_PAD gap)
    - Modifiers tinted lighter so the keyboard reads at a glance
    - Show current key assignment summary next to the key header
    - Keyboard legend + bolder combo preview
2026-06-24 Resize PCB under 100mm, finalize case STL, document AI usage
    - PCB outline trimmed to 68 x 99.68 mm (Stardance <100x100 limit);
    top mounting holes untouched, bottom edge + bottom holes moved up
    - Update STEP export to match resized board
    - Replace separate case parts with final combined STL (tray + open
    top frame, no-supports, PCB anti-flex support grid)
    - README: sync status checklist, new dimensions, add transparent
    "Use of AI" section (hardware by hand; AI assisted on firmware/app)
    Claude-Session: https://claude.ai/code/session_01VPvtJRWkd5XUxsE6SwSzo5
    [Hackpad-case-bottom.stl, Hackpad-case-top.stl, Hackpad-case.stl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]
2026-06-24 Add MIT license, finalize DRC-clean PCB, export JLCPCB gerbers
    - LICENSE: MIT covering software + hardware
    - README: license section -> MIT
    - PCB now DRC-clean (GND pour refilled, ENC_SW reconnected, stray
    GND track over encoder MP pad removed); only intentional baseline
    notices remain
    - export/hackpad-gerbers.zip: fab-ready gerbers + Excellon drill
    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
    [hackpad.kicad_pcb]
2026-06-24 Add "LG Hackpad" branding to PCB silkscreen, re-export gerbers
    Front silkscreen now carries the macropad name (required for YSWS
    submission). PCB still DRC-clean. Regenerated export/hackpad-gerbers.zip.
    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
    [hackpad.kicad_pcb]
2026-06-25 Make repo submission-ready: README with render, BOM, gallery
    - Embed full render, schematic/PCB/case photos (images/)
    - Add full BOM table and inspiration/challenges section
    - Point repo layout at the production gerbers + STEP/STL deliverables
2026-06-25 Add case as STEP for submission; update repo layout
2026-06-25 Add case STEP file to Case/ and fix README path
2026-06-25 Add BOM in CSV format; link from README
    [bom.csv]
2026-08-18 Add production/ folder with gerbers, case parts and final firmware
    Reviewer feedback: the submission needs one folder that contains
    everything required to actually build the Hackpad.
    - production/gerbers.zip: JLCPCB-ready fabrication files
    - production/case/: the case split into its 2 individual printable
    parts (bottom tray + top plate), separate watertight STLs, each
    centred and resting on Z=0, no supports needed
    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
    [Hackpad-Case-1-Bottom-Tray.stl, Hackpad-Case-2-Top-Plate.stl, bom.csv]
2026-10-02 Fix RP2040 encoder and add Mac QWERTZ profile pack
    Decode the existing D8/D9 encoder with background keypad scanning and cover rotation, bounce, startup and overflow with tests. Add Media, Code, Alltag and Browser profiles, preserve the previous configuration, and document hardware verification. Update documentation for the relocated Gerber archive.
    [code.py, encoder.py]
